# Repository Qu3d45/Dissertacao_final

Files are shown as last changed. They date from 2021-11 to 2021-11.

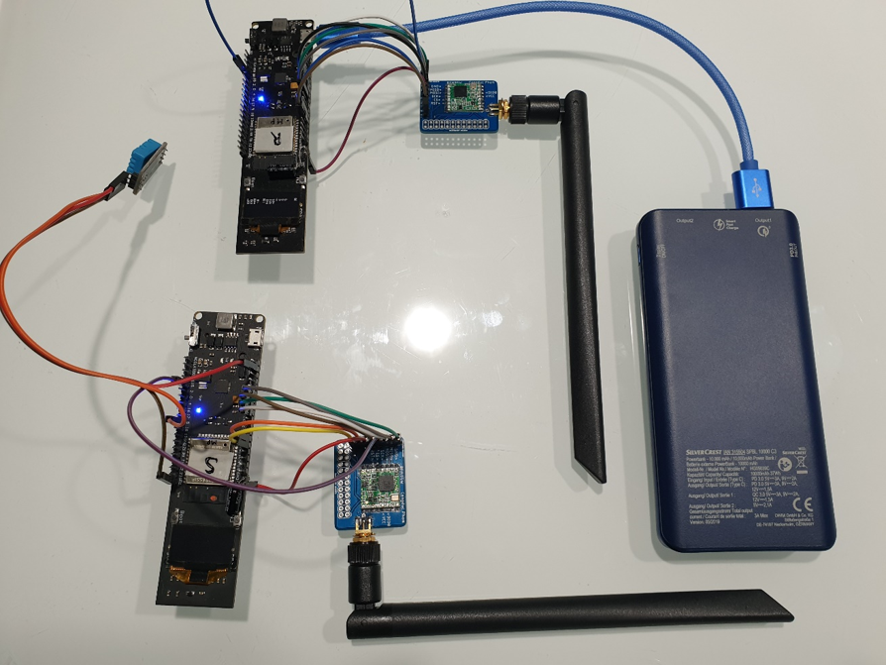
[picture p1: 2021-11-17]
Imagens_diagramas/lora_test.png

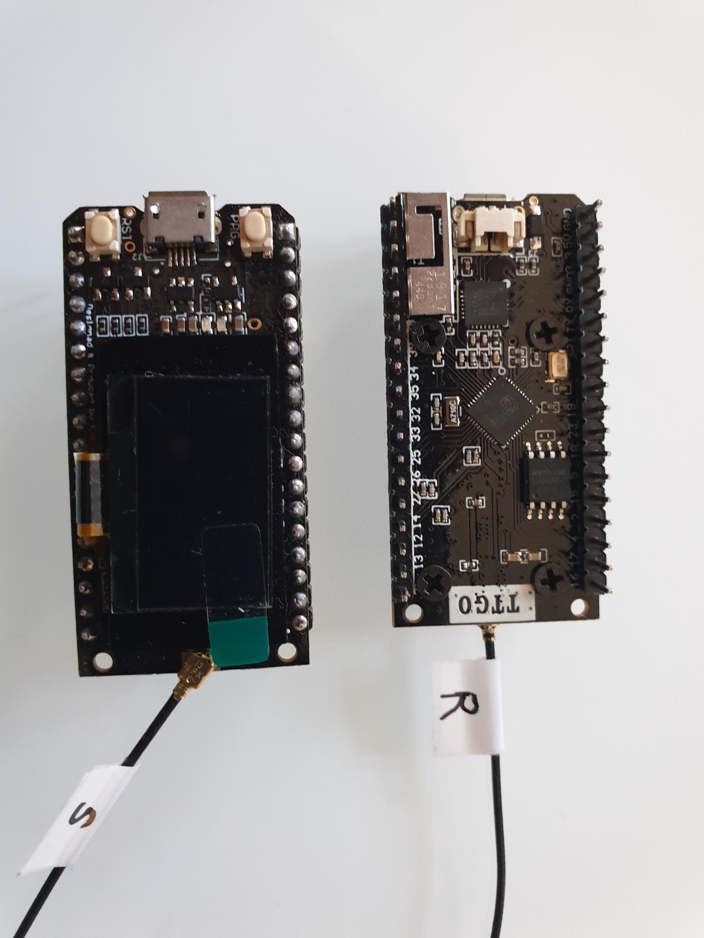
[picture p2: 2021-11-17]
Imagens_diagramas/esplora.png

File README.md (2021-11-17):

# Dissertação de Mestrado

## Mestrado em Internet das Coisas - Instituto Politécnico de Beja

<b>Título da Dissertação</b>
<br>Sistema de Monitorização de Canais de Rega

<b>Palavras-Chave</b>
<br>Qualidade/Quantidade da Água, Comunicações: LoRa, GSM, MQTT, Sistemas Embebidos, Pycom, MSP430, ESP32

<b>Tema da Dissertação</b>
<br>Projeto, desenvolvimento e implantação de sistema de monitorização de canais de água em canais de regadio. Apesar dos parâmetros de qualidade da água para regadio não serem tão restritos como no caso da água para consumo humano, existem alguns parâmetros em termos de concentração química de alguns elementos/nutrientes que são relevantes conhecer de modo a fazer uma rega mais eficiente compensando os fertilizantes em falta e diminuindo a administração de outros, o que se pode traduzir numa redução de custos económicos e num aumento da produção, e permitir fazer uma gestão dos recursos hídricos com base em dados concretos.

<br>Nesta dissertação pretende-se desenvolver e implentar um sistema de monitorização dos principais parâmetros da água de rega, e ainda a medição da quantidade de água utilizada. O sistema deve comunicar os dados, usando LoRa/GSM/LTE, para uma plataforma central, eventualmente passando por um sistema agregador, para posterior tratamento dos dados.

<b>Referências</b>
<br>Parameswari, M. & Moses, M. B. (2017). Online measurement of water quality and reporting system using prominent rule controller based on aqua care-IOT. Design Automation for Embedded Systems, doi:10.1007/s10617-017-9187-7.

<br>Pranata, A. A., Lee, J. M., & Kim, D. S. (2017). Towards an IoT-based water quality monitoring system with brokerless pub/sub architecture. In 2017 IEEE International Symposium on Local and Metropolitan Area Networks (LANMAN) (1–6), doi:10.1109/LANMAN.2017.7972166.

<br>Wong, B. P. & Kerkez, B. (2016). Real-time environmental sensor data: an application to water quality using web services. Environmental Modelling & Software, 84, 505-517, doi:10.1016/j.envsoft.2016.07.020.

<b>Orientador</b>
<br>João Carlos Martins
<br>Doutor em Engenharia Electrotécnica e de Computadores
<br>http://sepsi.ipbeja.pt/jcsm.html

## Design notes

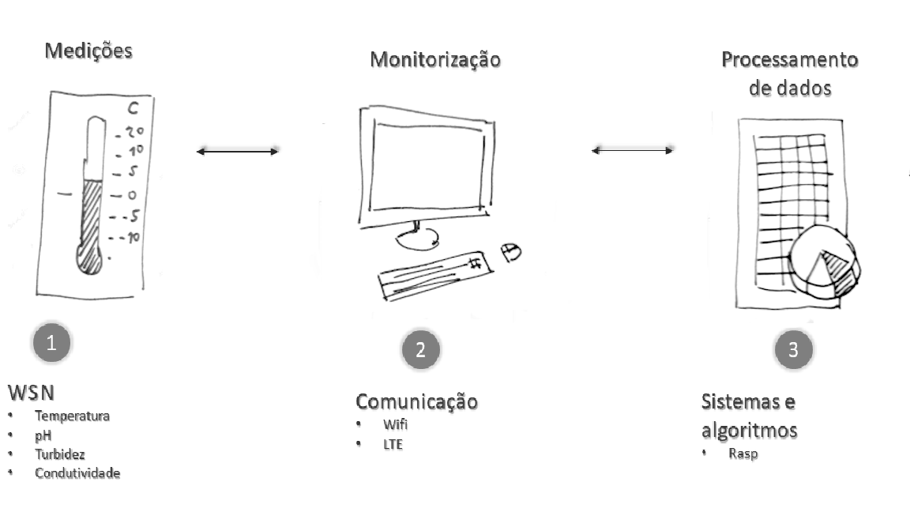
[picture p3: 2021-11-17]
Imagens_diagramas/paswari_edit.png

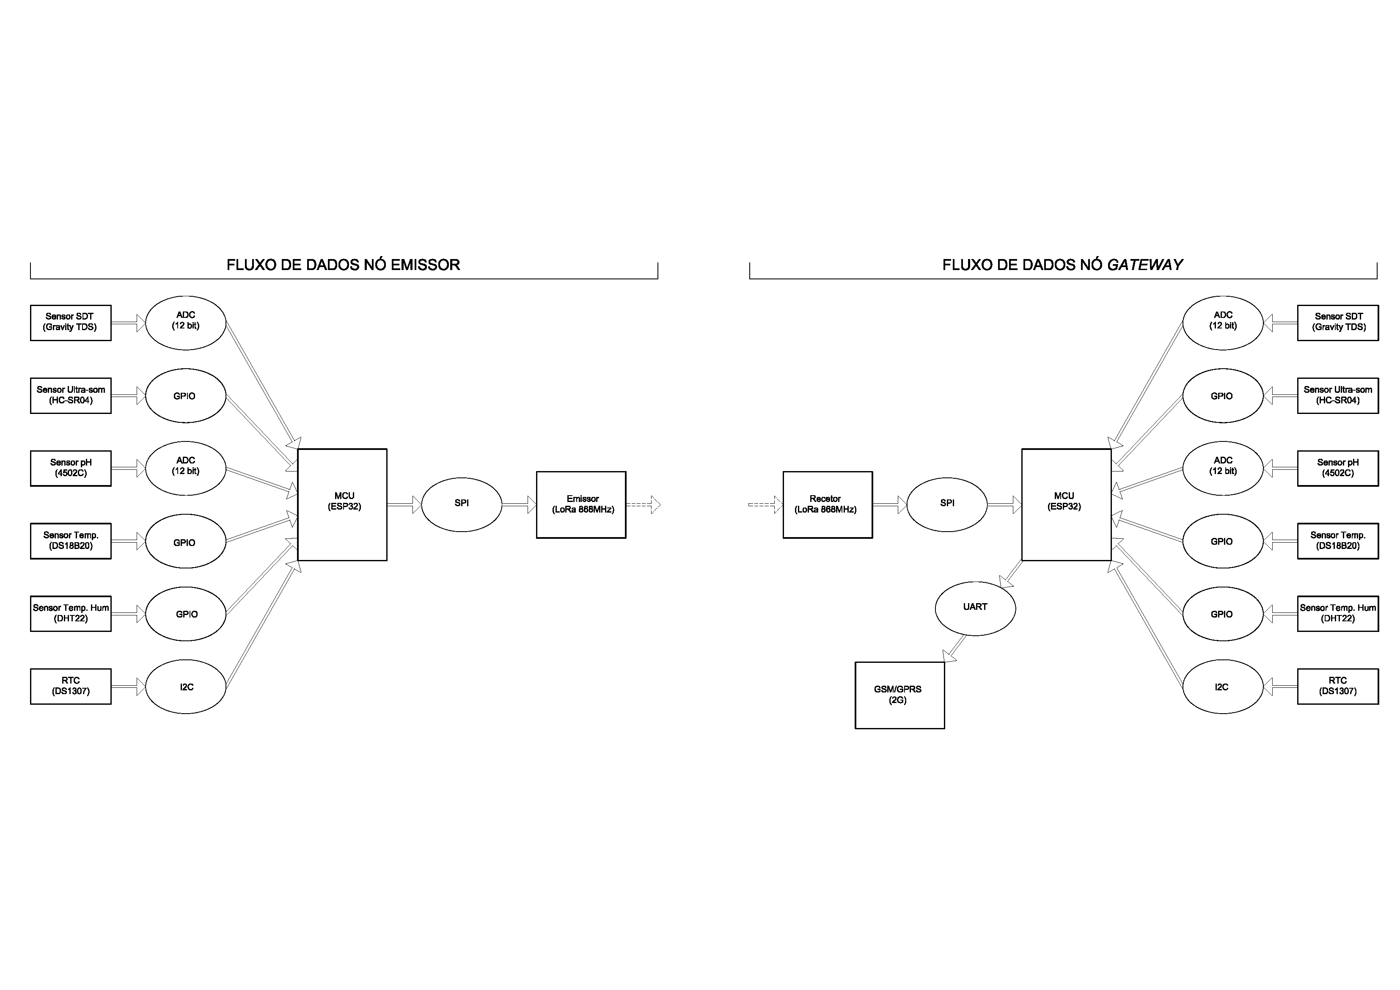
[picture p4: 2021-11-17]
Imagens_diagramas/fluxo.png

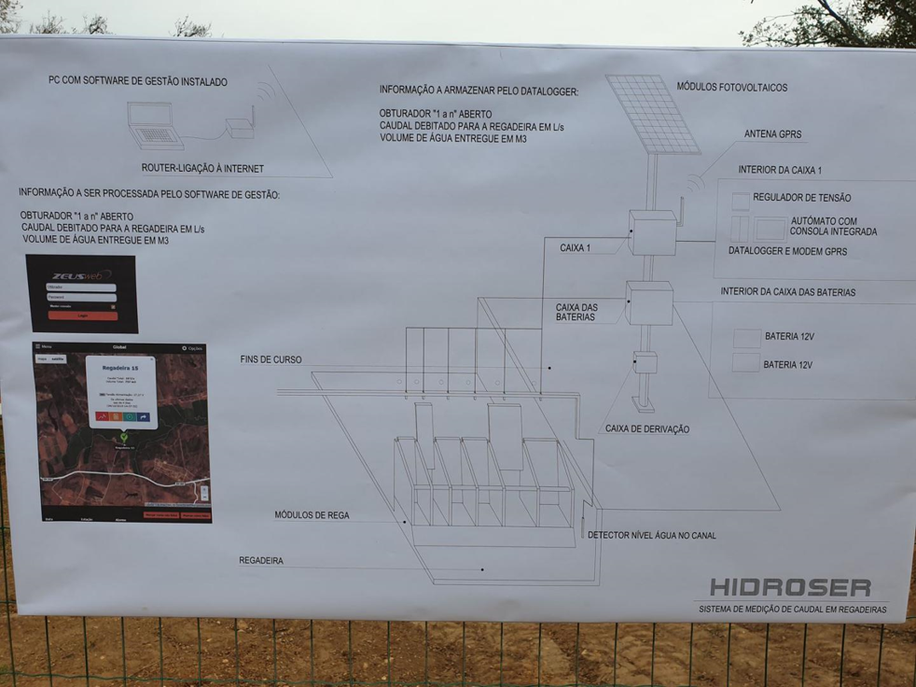
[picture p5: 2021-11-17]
Imagens_diagramas/hidroser.png

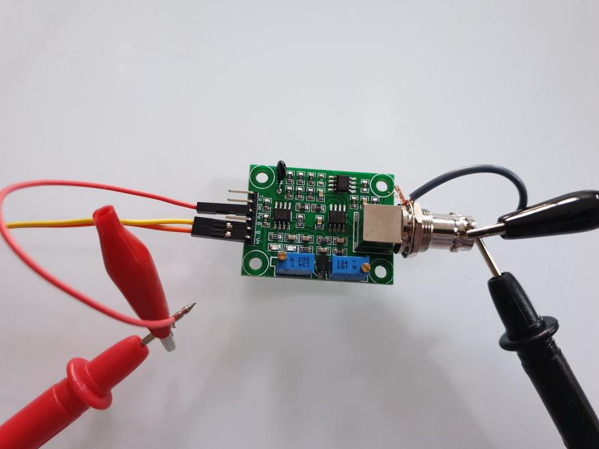
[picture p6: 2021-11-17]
Imagens_diagramas/ph_4502_3.png

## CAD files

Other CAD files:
Imagens_diagramas/Diagramas.dwg

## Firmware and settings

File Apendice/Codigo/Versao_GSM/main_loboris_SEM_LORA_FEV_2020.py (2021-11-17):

# Manuel Lameira
# Licence under MIT
# code for ESP32 with MicroPython Loboris

# For ADC1 only GPIOs 32-39 can be used as ADC inputs.
# For ADC2 gpios 4, 0, 2, 15, 13, 12, 14, 27, 25, 26 can be used as ADC inputs.

# DTH22 --> ESP32
# ---------------
# GND   --> GND
# VCC   --> 5v or 3.3v
# DAT   --> digitalPin 14

# DS18X20 --> ESP32
# -----------------
# VCC --> 3.3V with resistor
# GND --> GND
# DAT --> digitalPin 15

# ph  --> ESP32
# -----------------
# VCC --> 5V or 3.3V with resisto0r
# GND --> GND
# DAT --> digitalPin 34

# TDS --> ESP32
# --------------------
# VCC --> 3.3V
# A   --> Analog Pin 35
# GND --> GND

# SR04  --> ESP32
# --------------------
# VCC   --> 5V or 3.3V ATENCION: on 3.3V the range decresses
# Trig  --> DigitalPin 0
# Echo  --> DigitalPin 2
# GND   --> GND
# Speed of Sound = 343 m/s in dry air at 20ºC

# Channel ID 902540 - GSM/GPRS
# KEY IL9VIMCHEXM9H3W4
# GET https://api.thingspeak.com/update?api_key=IL9VIMCHEXM9H3W4&field1=0

# Channel ID 985682 - LoRa & GSM
# KEY 2IDFEOWYZCNDP7YW
# GET https://api.thingspeak.com/update?api_key=2IDFEOWYZCNDP7YW&field1=0

# Channel ID 1083373 - LoRa & LoRaWAN
# KEY V62MN5J6XDQXV22Q
# GET https://api.thingspeak.com/update?api_key=V62MN5J6XDQXV22Q&field1=0


from machine import Pin, I2C, time_pulse_us, Onewire, DHT, ADC, deepsleep
from time import sleep, sleep_ms, sleep_us

import socket
import machine
import time
import sys
import gsm

import json
import urequests
#import wlan

#import DS1307

# APN credentials (replace with yours)

GSM_APN = 'Qu3d45_ESP32'  # Your APN
GSM_USER = ''  # Your User
GSM_PASS = ''  # Your Pass

# Power on the GSM module

GSM_PWR = machine.Pin(4, machine.Pin.OUT)
GSM_RST = machine.Pin(5, machine.Pin.OUT)
GSM_MODEM_PWR = machine.Pin(23, machine.Pin.OUT)

GSM_PWR.value(0)
GSM_RST.value(1)
GSM_MODEM_PWR.value(1)

# Init PPPoS

# gsm.debug(True)  # Uncomment this to see more logs, investigate issues, etc.

gsm.start(tx=27, rx=26, apn=GSM_APN, user=GSM_USER, password=GSM_PASS)

sys.stdout.write('Waiting for AT command response...')
for retry in range(20):
    if gsm.atcmd('AT'):
        break
    else:
        sys.stdout.write('.')
        time.sleep_ms(5000)
else:
    raise Exception("Modem not responding!")
print()

print("Connecting to GSM...")
gsm.connect()

while gsm.status()[0] != 1:
    pass

print('IP:', gsm.ifconfig()[0])

# GSM connection is complete.
# You can now use modules like urequests, uPing, etc.


def ReadDS18(ds18_sensor):

    temp = ds18_sensor.convert_read()
    return temp


def Average(lst):
    # function to get average of a list
    return sum(lst) / len(lst)


def ReadPH(voltage, temp):
    # Calibration of probe
    # PH4502 with 5V --> pH 4 acidVoltage = 1.432V and pH 7 (pot calibration) neutralVoltage = 2.5V
    # with voltage divider --> pH 4 = 0.944V and pH 7 = 1.652V
    acidVoltage = 0.9440
    neutralVoltage = 1.6520

    if temp >= 25:
        temp_correction = 0.003 * (temp - 25)
    else:
        temp_correction = -0.003 * (temp - 25)

    slope = (7.0 - 4.0) / (- (acidVoltage - neutralVoltage) / 3.0)
    phValue = (slope * (voltage - neutralVoltage) /
               3.0) + temp_correction

    round(phValue, 2)
    return phValue


def ReadTDS(voltage, temp):
    # Temperature compensation to 25 °C reference value
    comp_Coefficente = 1 + 0.02 * (temp - 25)

    # compensated electrical conductivity
    comp_Voltage = voltage / comp_Coefficente

    # convert voltage value to tds value
    tds_value = ((133.42 * comp_Voltage**3) - (255.86 *
                                               comp_Voltage**2) + (857.39 * comp_Voltage)) * 0.5

    return tds_value


time_between_readings = 300000  # 5 min in s

#####----- RTC -----#####
#i2c = I2C(sda=Pin(21), scl=Pin(22))
#ds = DS1307.DS1307(i2c)

#date_init = ds.DateTime()

#####----- DS18X20 LOBORIS-----#####
ds18_pin = Onewire(15)
ds18_sensor = Onewire.ds18x20(ds18_pin, 0)

ds18_temp = ReadDS18(ds18_sensor)
print("Temperature: {0:.1f}°C".format(ds18_temp))

#####----- ph -----#####
pH = ADC(34)
pH.atten(ADC.ATTN_11DB)  # Reading range: 3.3V

# Creat empty list for value storage
buf_ph = []
sample_ph = range(10)

for i in sample_ph:
    buf_ph.append(pH.read())
    sleep(1)

avgValue_ph = Average(buf_ph)
phVoltage = (avgValue_ph / (4095/3.3))

pH_final = round(ReadPH(phVoltage, ds18_temp), 1)
print(pH_final, "ph")

#####----- TDS -----#####

# Pin definition and ADC initialization
tds = ADC(35)
tds.atten(ADC.ATTN_11DB)  # Reading range: 3.3V

buf_tds = []
sample_tds = range(5)

for i in sample_tds:
    buf_tds.append(tds.read())
    sleep(1)

avgValue_tds = Average(buf_tds)
tdsVoltage = (avgValue_tds * (3.3/4095))  # read the voltage in mV

tdsValue = round(ReadTDS(tdsVoltage, ds18_temp), 3)
print(tdsValue, " ppm")

#####----- DHT22 -----#####
dht_sensor = DHT(14, DHT.DHT2X)

result, temperature, humidity = dht_sensor.read()

x = result
temp_dht22 = float(temperature)
hum_dht22 = int(humidity)
print(temp_dht22, " ºC")
print(hum_dht22, " %")


#####----- Water flow HC-SR04 -----#####

trig = Pin(0, Pin.OUT)
echo = Pin(2, Pin.IN)

timeout_us = 25000  # no need to wait more then sensor's range limit (4,00 m)

sensor_hight = 150  # cm

trig.value(1)
sleep_us(10)
trig.value(0)

duration = time_pulse_us(echo, 1, timeout_us)

if duration < 0:
    print("Out of range")
    pass
else:
    # To calculate the distance we get the pulse_time and divide it by 2
    # (the pulse walk the distance twice)
    # the sound speed on air (343.2 m/s), that It's equivalent to
    # 0.034320 cm/us that is 1cm each 29.1us
    # Calculate the Speed of Sound in M/S
    sound_comp = (331.4 + (0.606 * temp_dht22) + (0.0124 * hum_dht22))/10000
#    print(sound_comp, " sound_comp")

    distance = (duration / 2) * (sound_comp)  # m/us
#    print(distance, " distance")

    water_hight = sensor_hight - distance  # cm
#    print(water_hight, " water_hight2")

    water_hight_m = water_hight/100

    discharge = (0.21579*(water_hight_m**(5/3))) / \
        ((water_hight_m + 0.47918)**(2/3))
    print(discharge, " m3/s")

    # Use only with deep sleep

    # date_flow_now = ds.DateTime()

    # total_discharge = (date_flow_now - date_init) * discharge
    # in seconds! the 40s is the time need to run the code
    total_discharge = discharge * ((time_between_readings/60)+40)

#####----- Thingspeak -----#####
url_gateway = "https://api.thingspeak.com/update?api_key=IL9VIMCHEXM9H3W4&field1={}&field2={}&field3={}&field4={}&field5={}&field6={}&field7={}".format(
    ds18_temp, pH_final, discharge, tdsValue, temp_dht22, hum_dht22, total_discharge)


update_gateway = urequests.get(url_gateway)

# sleep(time_between_readings)

# sleep for 5 min (300000 miliseconds)
deepsleep(time_between_readings)

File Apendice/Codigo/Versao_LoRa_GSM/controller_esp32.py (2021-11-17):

from machine import Pin, SPI, reset
from controller import Controller


class ESP32Controller(Controller):

    # LoRa config
    PIN_ID_FOR_LORA_RESET = 33

    PIN_ID_FOR_LORA_SS = 15
    PIN_ID_SCK = 14
    PIN_ID_MOSI = 13
    PIN_ID_MISO = 12

    PIN_ID_FOR_LORA_DIO0 = 32
    PIN_ID_FOR_LORA_DIO1 = None
    PIN_ID_FOR_LORA_DIO2 = None
    PIN_ID_FOR_LORA_DIO3 = None
    PIN_ID_FOR_LORA_DIO4 = None
    PIN_ID_FOR_LORA_DIO5 = None


    # ESP config
    ON_BOARD_LED_PIN_NO = 2
    ON_BOARD_LED_HIGH_IS_ON = True
    GPIO_PINS = (0, 1, 2, 3, 4, 5, 6, 7, 8, 9, 10, 11,
                 12, 13, 14, 15, 16, 17, 18, 19, 21, 22,
                 23, 25, 26, 27, 32, 34, 35, 36, 37, 38, 39)


    def __init__(self,
                 pin_id_led = ON_BOARD_LED_PIN_NO,
                 on_board_led_high_is_on = ON_BOARD_LED_HIGH_IS_ON,
                 pin_id_reset = PIN_ID_FOR_LORA_RESET,
                 blink_on_start = (2, 0.5, 0.5)):

        super().__init__(pin_id_led,
                         on_board_led_high_is_on,
                         pin_id_reset,
                         blink_on_start)


    def prepare_pin(self, Pin_id, in_out = Pin.OUT):
        if Pin_id is not None:
            pin = Pin(Pin_id, in_out)
            new_pin = Controller.Mock()
            new_pin.Pin_id = Pin_id
            new_pin.value = pin.value

            if in_out == Pin.OUT:
                new_pin.low = lambda : pin.value(0)
                new_pin.high = lambda : pin.value(1)
            else:
                new_pin.irq = pin.irq

            return new_pin


    def prepare_irq_pin(self, pin_id):
        pin = self.prepare_pin(pin_id, Pin.IN)
        if pin:
            pin.set_handler_for_irq_on_rising_edge = lambda handler: pin.irq(handler = handler, trigger = Pin.IRQ_RISING)
            pin.detach_irq = lambda : pin.irq(handler = None, trigger = 0)
            return pin


    def get_spi(self):
        spi = None

        try:
            spi = SPI(baudrate = 10000000, polarity = 0, phase = 0, bits = 8, firstbit = SPI.MSB,
                      sck = Pin(self.PIN_ID_SCK, Pin.OUT, Pin.PULL_DOWN),
                      mosi = Pin(self.PIN_ID_MOSI, Pin.OUT, Pin.PULL_UP),
                      miso = Pin(self.PIN_ID_MISO, Pin.IN, Pin.PULL_UP))
            #spi.init()

        except Exception as e:
            print(e)
            if spi:
                spi.deinit()
                spi = None
            reset()  # in case SPI is already in use, need to reset.

        return spi


    def prepare_spi(self, spi):

        if spi:
            new_spi = Controller.Mock()

            def transfer(pin_ss, address, value = 0x00):
                response = bytearray(1)

                pin_ss.low()

                spi.write(bytes([address]))
                spi.write_readinto(bytes([value]), response)

                pin_ss.high()

                return response

            new_spi.transfer = transfer
            new_spi.close = spi.deinit
            return new_spi


    def __exit__(self):
        self.spi.close()

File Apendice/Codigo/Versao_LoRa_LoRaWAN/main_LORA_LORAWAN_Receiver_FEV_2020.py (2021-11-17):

import config_lora
from sx127x import SX127x
from controller_esp32 import ESP32Controller

from ssd1306_i2c import Display

from time import sleep, sleep_ms, sleep_us
import network
from umqtt.simple import MQTTClient


# ThingSpeak Credentials:
SERVER = "mqtt.thingspeak.com"
CHANNEL_ID = "1083373"
WRITE_API_KEY = "V62MN5J6XDQXV22Q"
PUB_TIME_SEC = 30

# MQTT client object
client = MQTTClient("umqtt_client", SERVER)

# Create the MQTT topic string
topic = "channels/" + CHANNEL_ID + "/publish/" + WRITE_API_KEY

# WiFi Credentials
WiFi_SSID = "LamyS9"
WiFi_PASS = "nkzs4379"


def do_connect():
    wlan = network.WLAN(network.STA_IF)
    wlan.active(True)
    if not wlan.isconnected():
        print('connecting to network...')
        wlan.connect(WiFi_SSID, WiFi_PASS)
        while not wlan.isconnected():
            pass
    print('network config:', wlan.ifconfig())


def receive(lora):
    print("LoRa Receiver")

    display = Display()

    while True:
        lora.receivedPacket()

        lora.blink_led()

        try:
            payload = lora.read_payload()

            #display.show_text_wrap("{} {} RSSI: {}".format(ident, payload.decode(), lora.packetRssi()), 2)
            #print("*** Received message ***\n{}".format(payload.decode()))

            data_recived = payload.decode()
            # print(data_recived)
            split_data_recived = data_recived.split()
            # print(split_data_recived)
            ds18_temp, pH_final, discharge, tdsValue, temp_dht22, hum_dht22, total_discharge = split_data_recived

            # print(ds18_temp)
            # print(pH_final)
            # print(discharge)
            # print(tdsValue)
            # print(temp_dht22)
            # print(hum_dht22)
            # print(total_discharge)
            # # Save to file if needed
            # # with open("recived.txt", mode='a') as file:
            # #     file.write('data recived raw: {} \n'.format(payload))
            display.show_text_wrap("{} {} {} {} {} {} {} ".format(
                ds18_temp, pH_final, discharge, tdsValue, temp_dht22, hum_dht22, total_discharge), 2)

            mqtt_payload = "field1="+str(ds18_temp)+"&field2="+str(pH_final)+"&field3="+str(discharge)+"&field4="+str(
                tdsValue)+"&field5="+str(temp_dht22)+"&field6="+str(hum_dht22)+"&field7="+str(total_discharge)

            client.connect()
            client.publish(topic, mqtt_payload)
            client.disconnect()
            sleep(PUB_TIME_SEC)

        except Exception as e:
            print(e)
        #display.show_text("RSSI: {}\n".format(lora.packetRssi()), 10, 10)
        #print("with RSSI: {}\n".format(lora.packetRssi))


controller = ESP32Controller()
lora = controller.add_transceiver(SX127x(name='LoRa'),
                                  pin_id_ss=ESP32Controller.PIN_ID_FOR_LORA_SS,
                                  pin_id_RxDone=ESP32Controller.PIN_ID_FOR_LORA_DIO0)
do_connect()

receive(lora)
